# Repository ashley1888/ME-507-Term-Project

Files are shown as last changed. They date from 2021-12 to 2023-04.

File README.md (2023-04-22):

# ME-507-Term-Project
Claw Machine by

Michael Yiu and Ashley Humpal

Fall 2021

The code in this repository aims to control a claw machine and have it go to a destination and pick up objects.

For formal documentation please refer to: https://ashley1888.github.io/ME-507-Term-Project/

This repository contains:

controller_task.cpp

controller_task.h

X_Motor_task.cpp

X_Motor_task.h

Y_Motor_task.cpp

Y_Motor_task.h

Z_Motor_task.cpp

Z_Motor_task.h

Gripper_Motor_task.cpp

Gripper_Motor_task.h

motor_driver.cpp

motor_driver.h

shares.h

main.cpp

Encoder driver files were provided by our professor, Dr. Ridgely and their source code can be found at:
https://github.com/spluttflob/ME507-Support/blob/master/examples/encoder_counter.cpp
https://github.com/spluttflob/ME507-Support/blob/master/examples/encoder_counter.h

Each file contains doxygen style documentation.

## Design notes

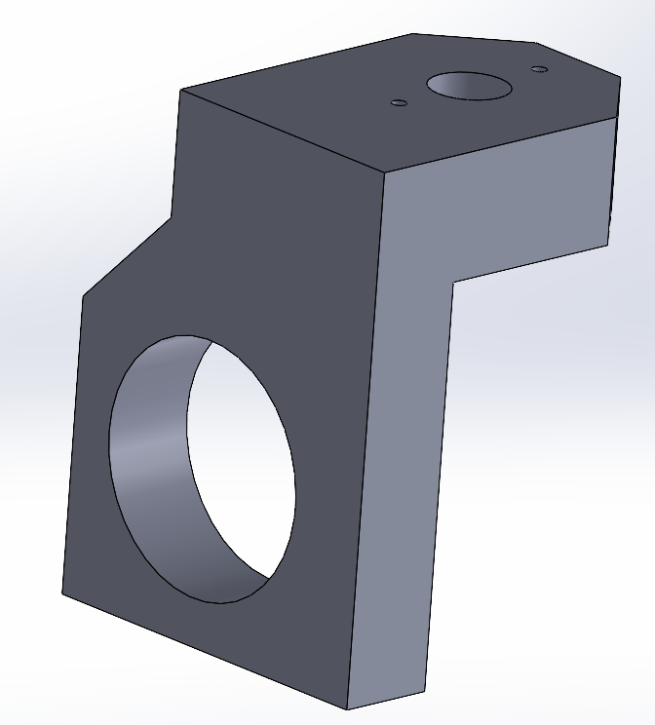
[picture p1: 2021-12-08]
docs/lead_screw_to_gripper.png

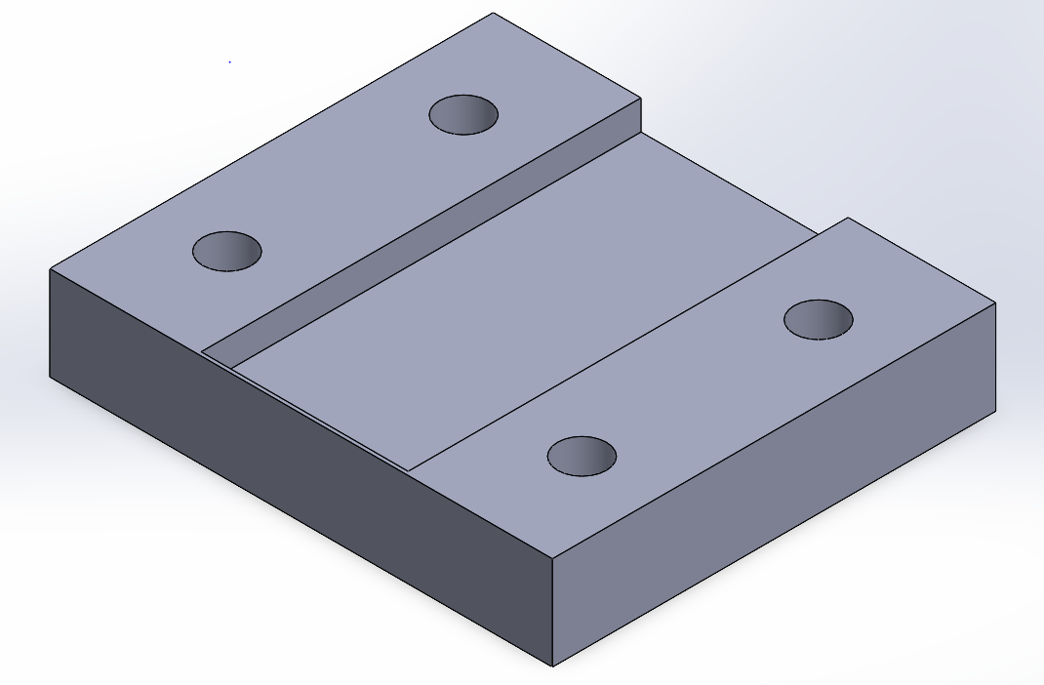
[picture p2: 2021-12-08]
docs/belt_holder.png

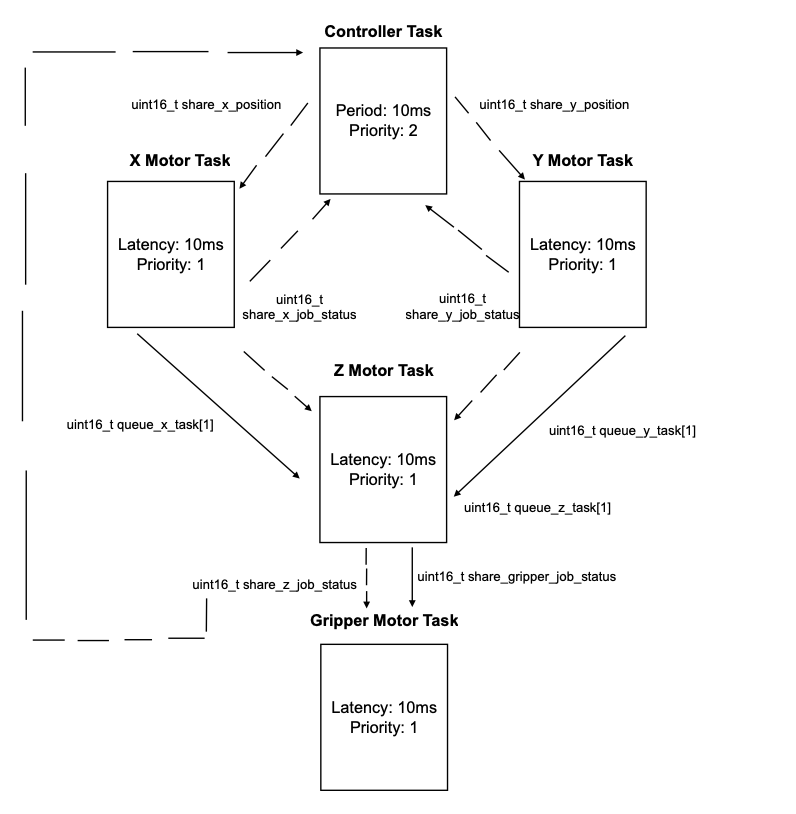
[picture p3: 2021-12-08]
docs/taskdiagram.png

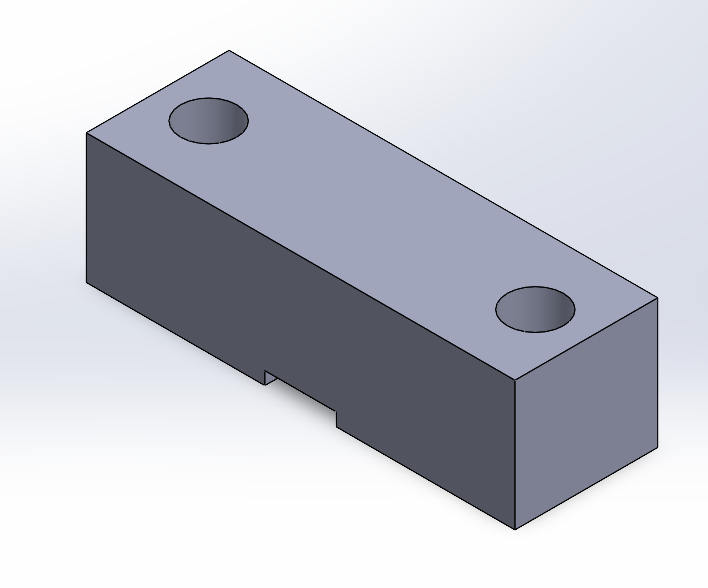
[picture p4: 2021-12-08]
docs/belt_clamp.png

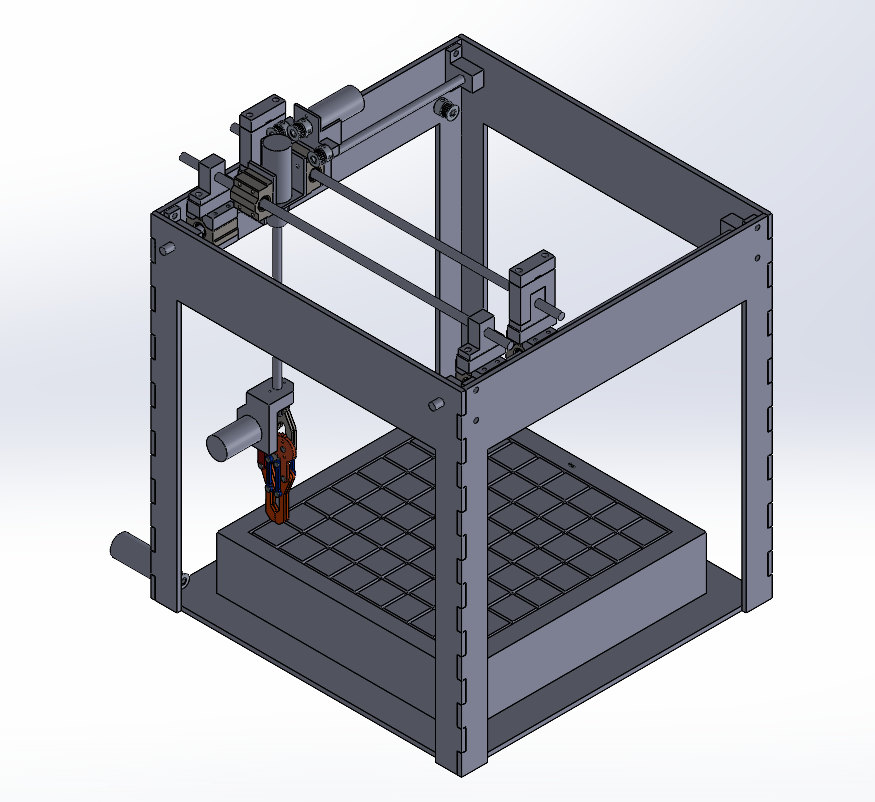
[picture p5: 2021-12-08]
docs/isometric_view.png

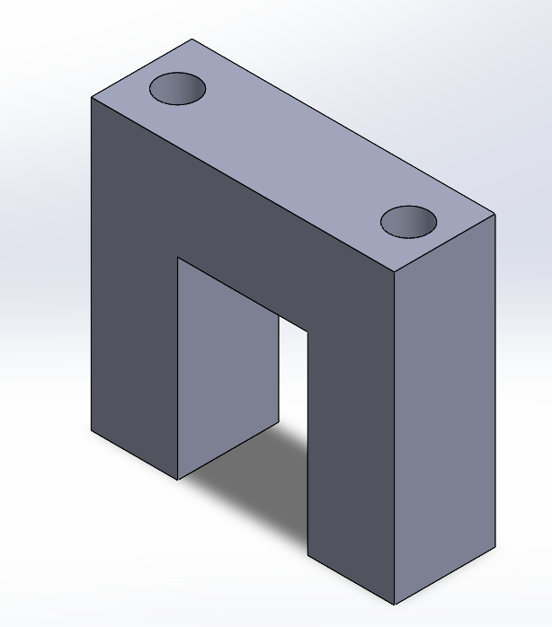
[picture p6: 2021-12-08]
docs/linear_rod_support.png

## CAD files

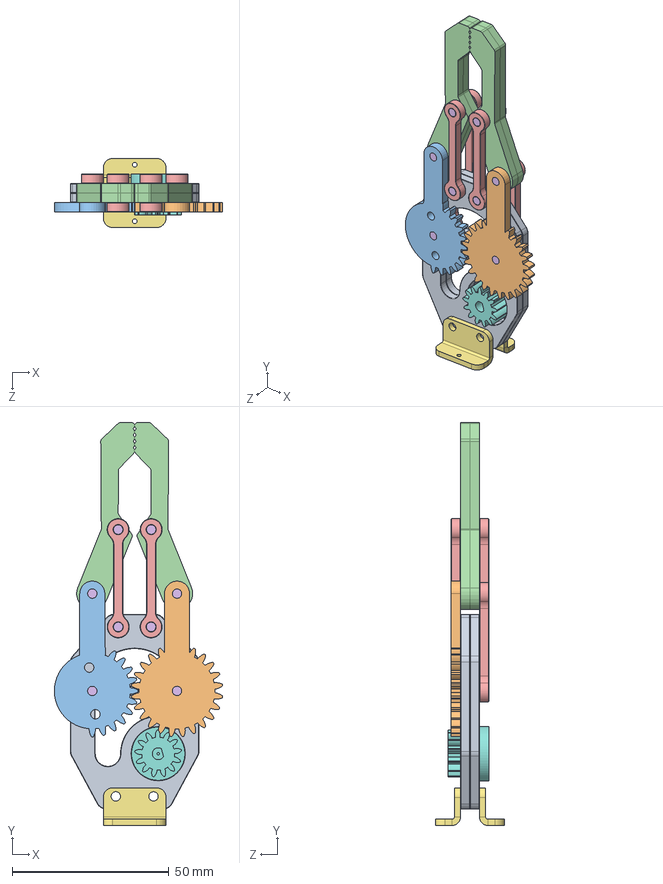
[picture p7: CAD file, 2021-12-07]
CAD/Gripper Assembly.SLDASM
53.6 x 128.4 x 22.0 mm

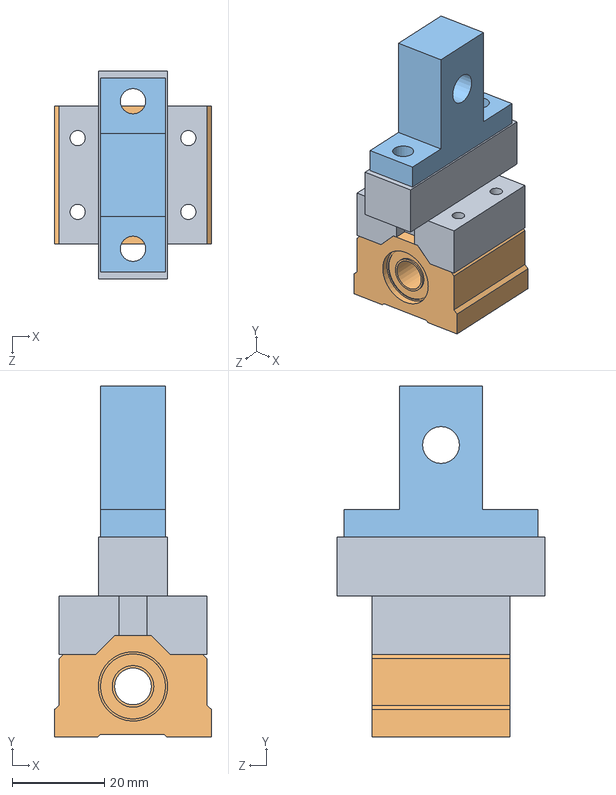
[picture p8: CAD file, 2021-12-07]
CAD/3D Printed Parts/Shaft Bearing.SLDASM
34.1 x 76.1 x 45.0 mm
Shaft Support to Linear Bearing
Linear Ball Bearing
Linear Rod Support

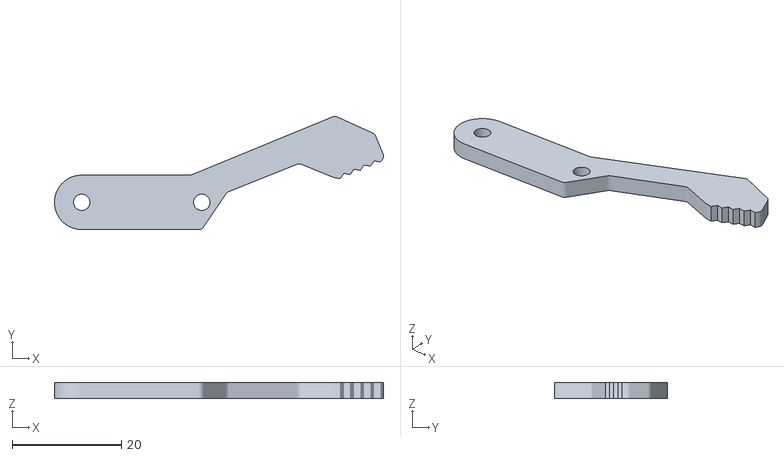
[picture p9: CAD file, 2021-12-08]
CAD/3D Printed Parts/.stl Files/Part1-1 (x4).STL
60.3 x 20.7 x 3.00

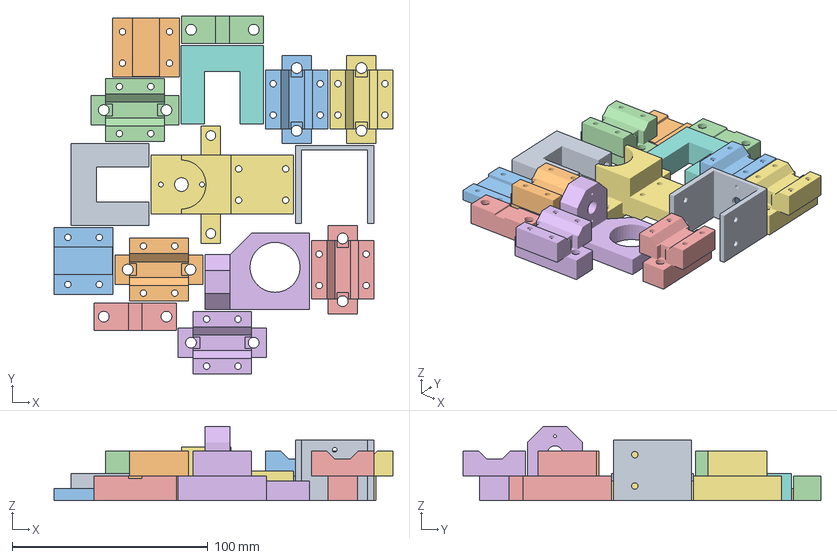
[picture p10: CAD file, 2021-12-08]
CAD/3D Printed Parts/Print Files/Large Pieces.3mf
172.8 x 182.7 x 38.0 mm
Z Motor Support (x1).STL
Shaft Support to Linear Bearing (x6).STL(5)
Shaft Support to Linear Bearing (x6).STL(4)
Shaft Support to Linear Bearing (x6).STL(3)
Shaft Support to Linear Bearing (x6).STL(2)
Shaft Support to Linear Bearing (x6).STL(1)
Shaft Support to Linear Bearing (x6).STL
Linear Rod Support Belt Holder (x2).STL(1)
Linear Rod Support Belt Holder (x2).STL
Belt Holder (x2).STL(1)
Belt Holder (x2).STL
Belt Clamp (x2).STL(1)
Belt Clamp (x2).STL
Lead Screw to Gripper (x1).STL(1)
Motor Support to Linear Bearing (x1).STL

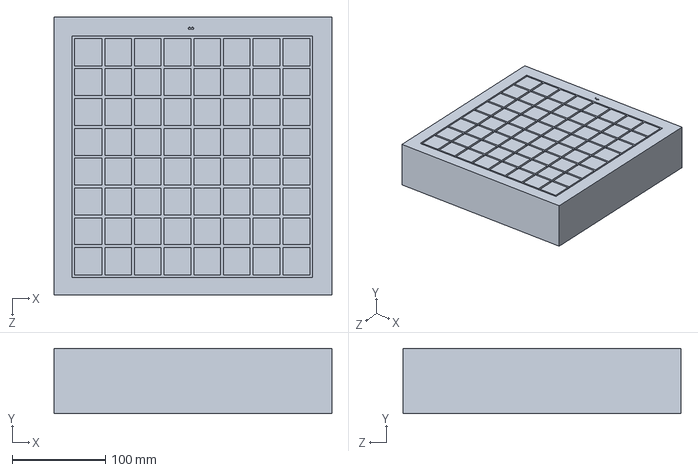
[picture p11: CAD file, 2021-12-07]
CAD/Frame/Chessboard.SLDPRT
298.4 x 69.8 x 298.4 mm

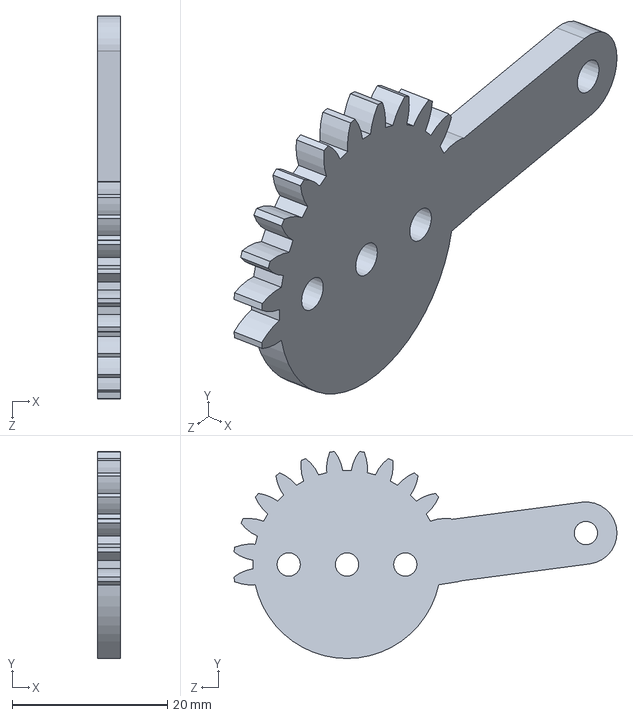
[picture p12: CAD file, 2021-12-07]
CAD/Gripper/part5-5.SLDPRT
3.00 x 26.6 x 49.3 mm

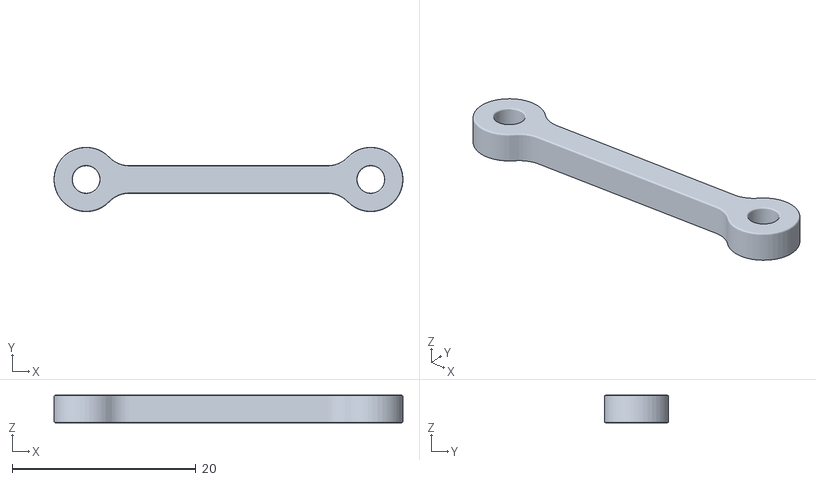
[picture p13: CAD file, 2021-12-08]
CAD/3D Printed Parts/.stl Files/Part2-2 (x6).STL
38.0 x 6.99 x 3.00

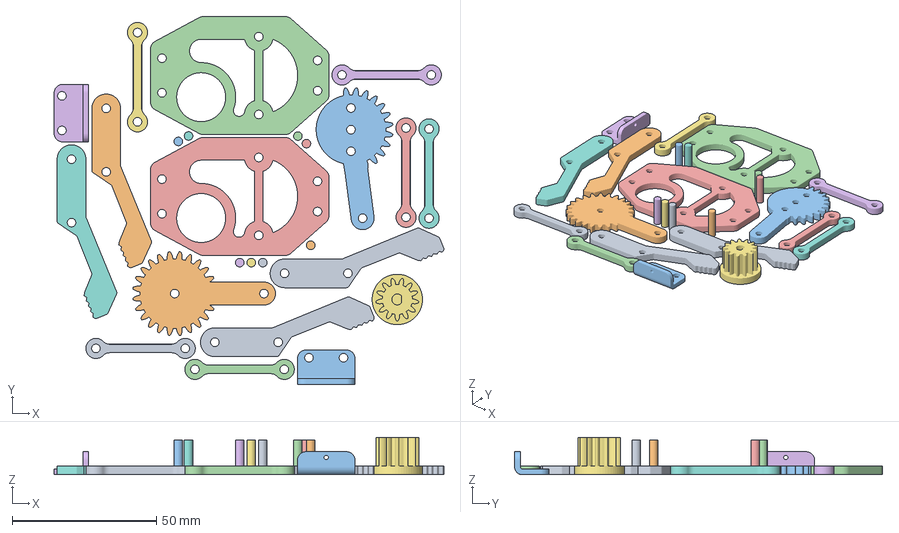
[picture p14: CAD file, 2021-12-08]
CAD/3D Printed Parts/Print Files/Small Pieces.3mf
135.3 x 127.7 x 13.0 mm
Part1-1 (x4).STL
part4-4 (x1).STL
part5-5 (x1).STL
Part2-2 (x6).STL
Part3-3 (x2).STL
Part7-7 (x2).STL
part8-8 (x1).STL
Part1-1 (x4).STL(1)
Part1-1 (x4).STL(2)
Part1-1 (x4).STL(3)
Part7-7 (x2).STL(1)
Part3-3 (x2).STL(1)
Part2-2 (x6).STL(1)
Part2-2 (x6).STL(2)
Part2-2 (x6).STL(3)
Part2-2 (x6).STL(4)
Part2-2 (x6).STL(5)
Part6-6 (x8).STL
Part6-6 (x8).STL(1)
Part6-6 (x8).STL(2)
Part6-6 (x8).STL(3)
Part6-6 (x8).STL(4)
Part6-6 (x8).STL(5)
Part6-6 (x8).STL(6)
Part6-6 (x8).STL(7)

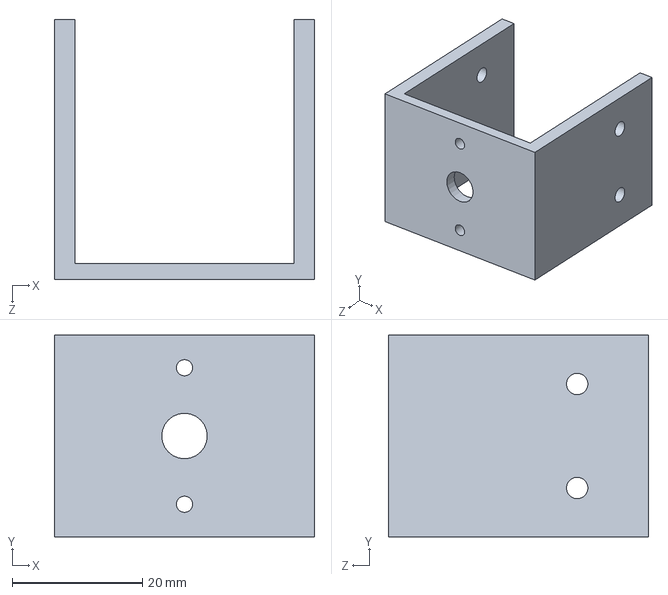
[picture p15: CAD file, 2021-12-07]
CAD/3D Printed Parts/Z Motor Support.SLDPRT
40.0 x 31.0 x 40.0 mm

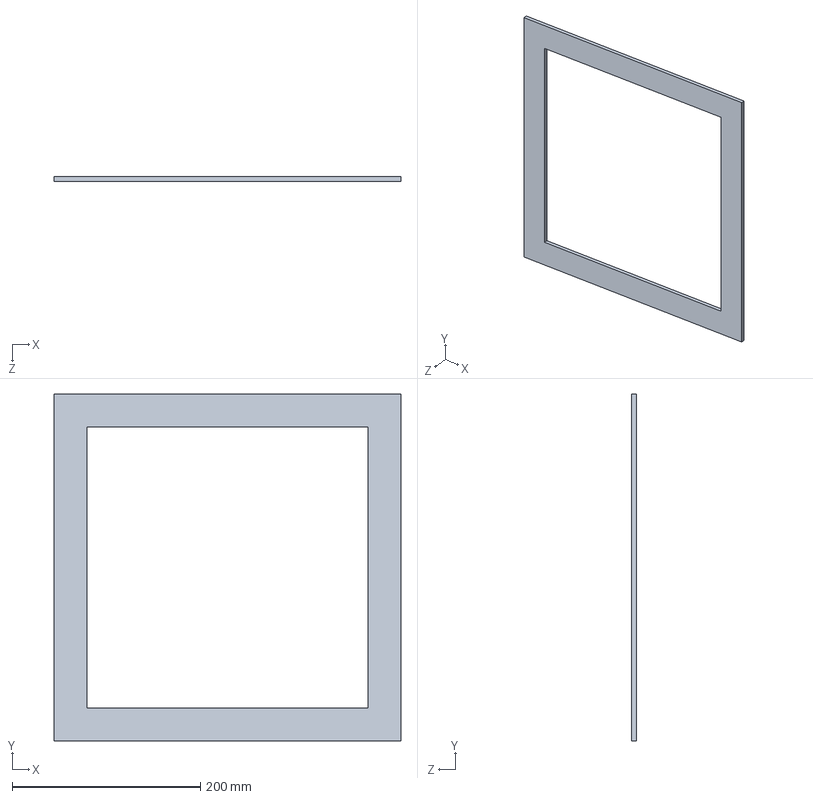
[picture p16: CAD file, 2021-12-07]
CAD/Frame/Mount.SLDPRT
368.3 x 368.3 x 5.33 mm

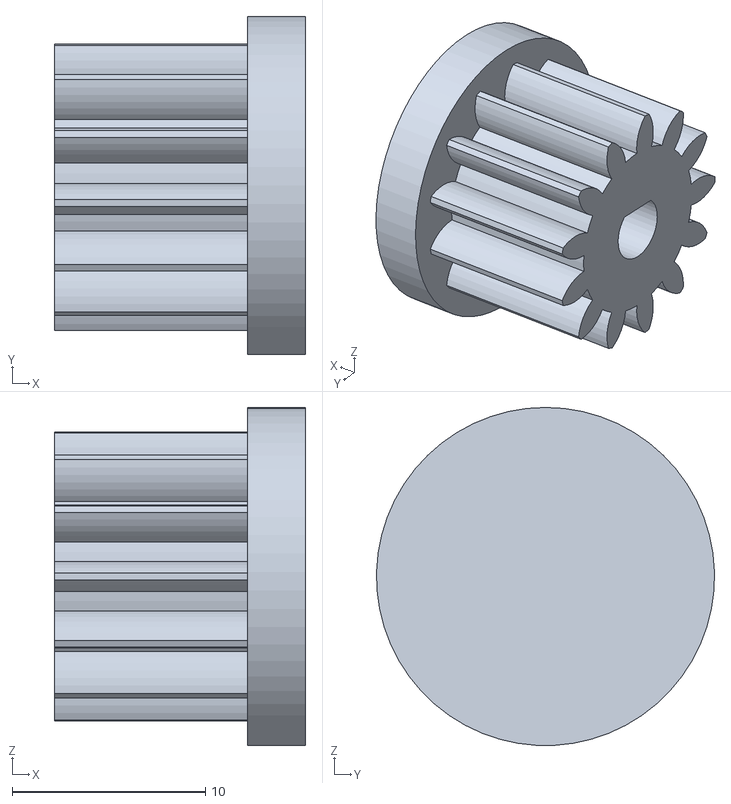
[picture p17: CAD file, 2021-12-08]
CAD/3D Printed Parts/.stl Files/part8-8 (x1).STL
13.0 x 17.5 x 17.5

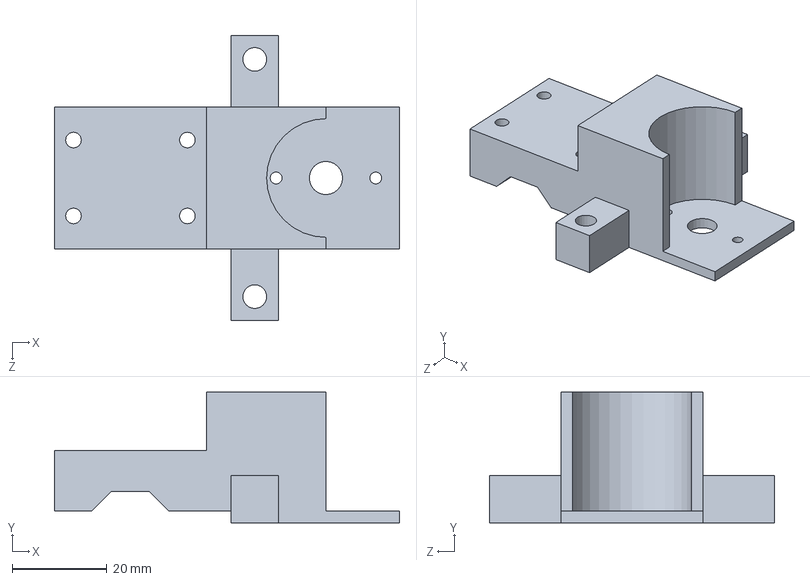
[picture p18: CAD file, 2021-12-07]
CAD/3D Printed Parts/Motor Support to Linear Bearing.SLDPRT
72.7 x 27.5 x 60.0 mm

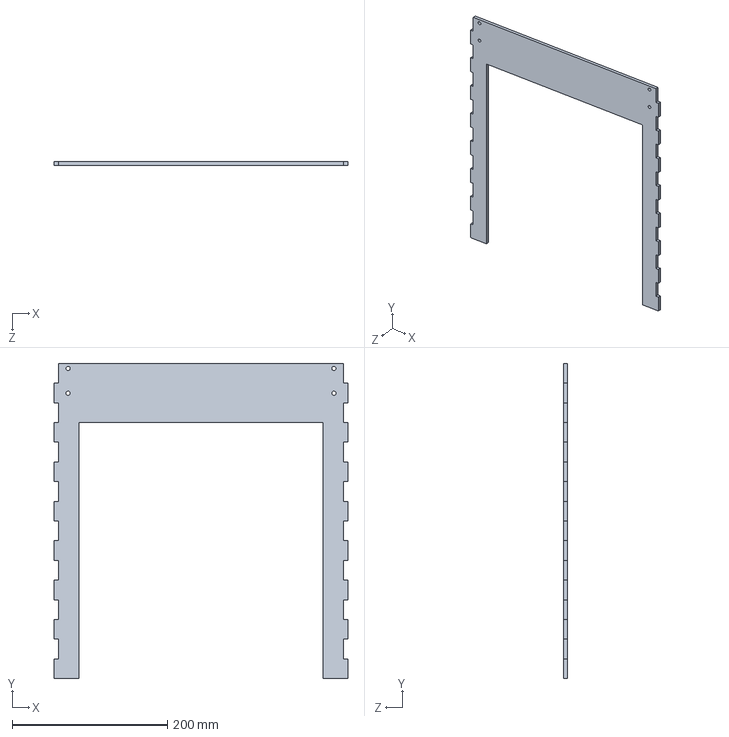
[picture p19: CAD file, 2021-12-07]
CAD/Frame/Long Side.SLDPRT
378.7 x 406.4 x 5.21 mm

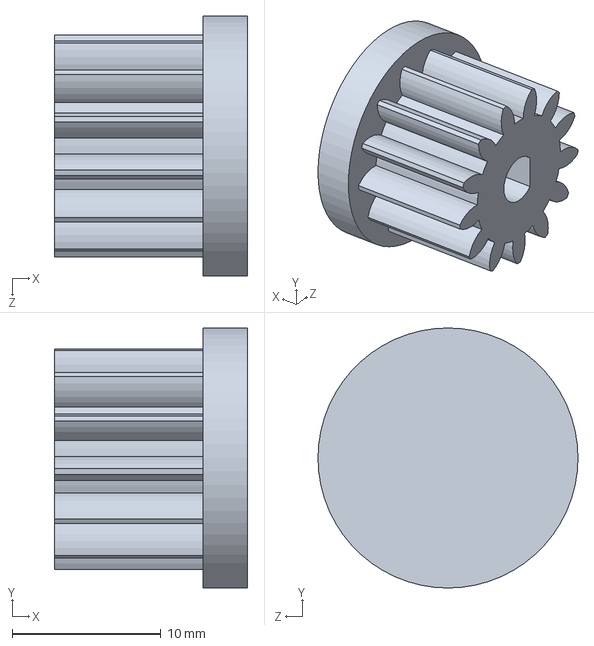
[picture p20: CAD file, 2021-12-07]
CAD/Gripper/part8-8.SLDPRT
13.0 x 17.5 x 17.5 mm

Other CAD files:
CAD/Gripper/Part1-1.SLDPRT
CAD/3D Printed Parts/.stl Files/part5-5 (x1).STL
CAD/3D Printed Parts/Belt Clamp.SLDPRT
CAD/3D Printed Parts/.stl Files/Belt Clamp (x2).STL
CAD/3D Printed Parts/.stl Files/Belt Holder (x2).STL
CAD/3D Printed Parts/.stl Files/Lead Screw to Gripper (x1).STL
CAD/3D Printed Parts/.stl Files/Linear Rod Support Belt Holder (x2).STL
CAD/3D Printed Parts/.stl Files/Motor Support to Linear Bearing (x1).STL
CAD/3D Printed Parts/.stl Files/Part3-3 (x2).STL
CAD/3D Printed Parts/.stl Files/Part6-6 (x8).STL
CAD/3D Printed Parts/.stl Files/Part7-7 (x2).STL
CAD/3D Printed Parts/.stl Files/Shaft Support to Linear Bearing (x6).STL
CAD/3D Printed Parts/.stl Files/Z Motor Support (x1).STL
CAD/3D Printed Parts/.stl Files/part4-4 (x1).STL
CAD/3D Printed Parts/Belt Holder.SLDPRT
CAD/3D Printed Parts/Lead Screw to Gripper.SLDPRT
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

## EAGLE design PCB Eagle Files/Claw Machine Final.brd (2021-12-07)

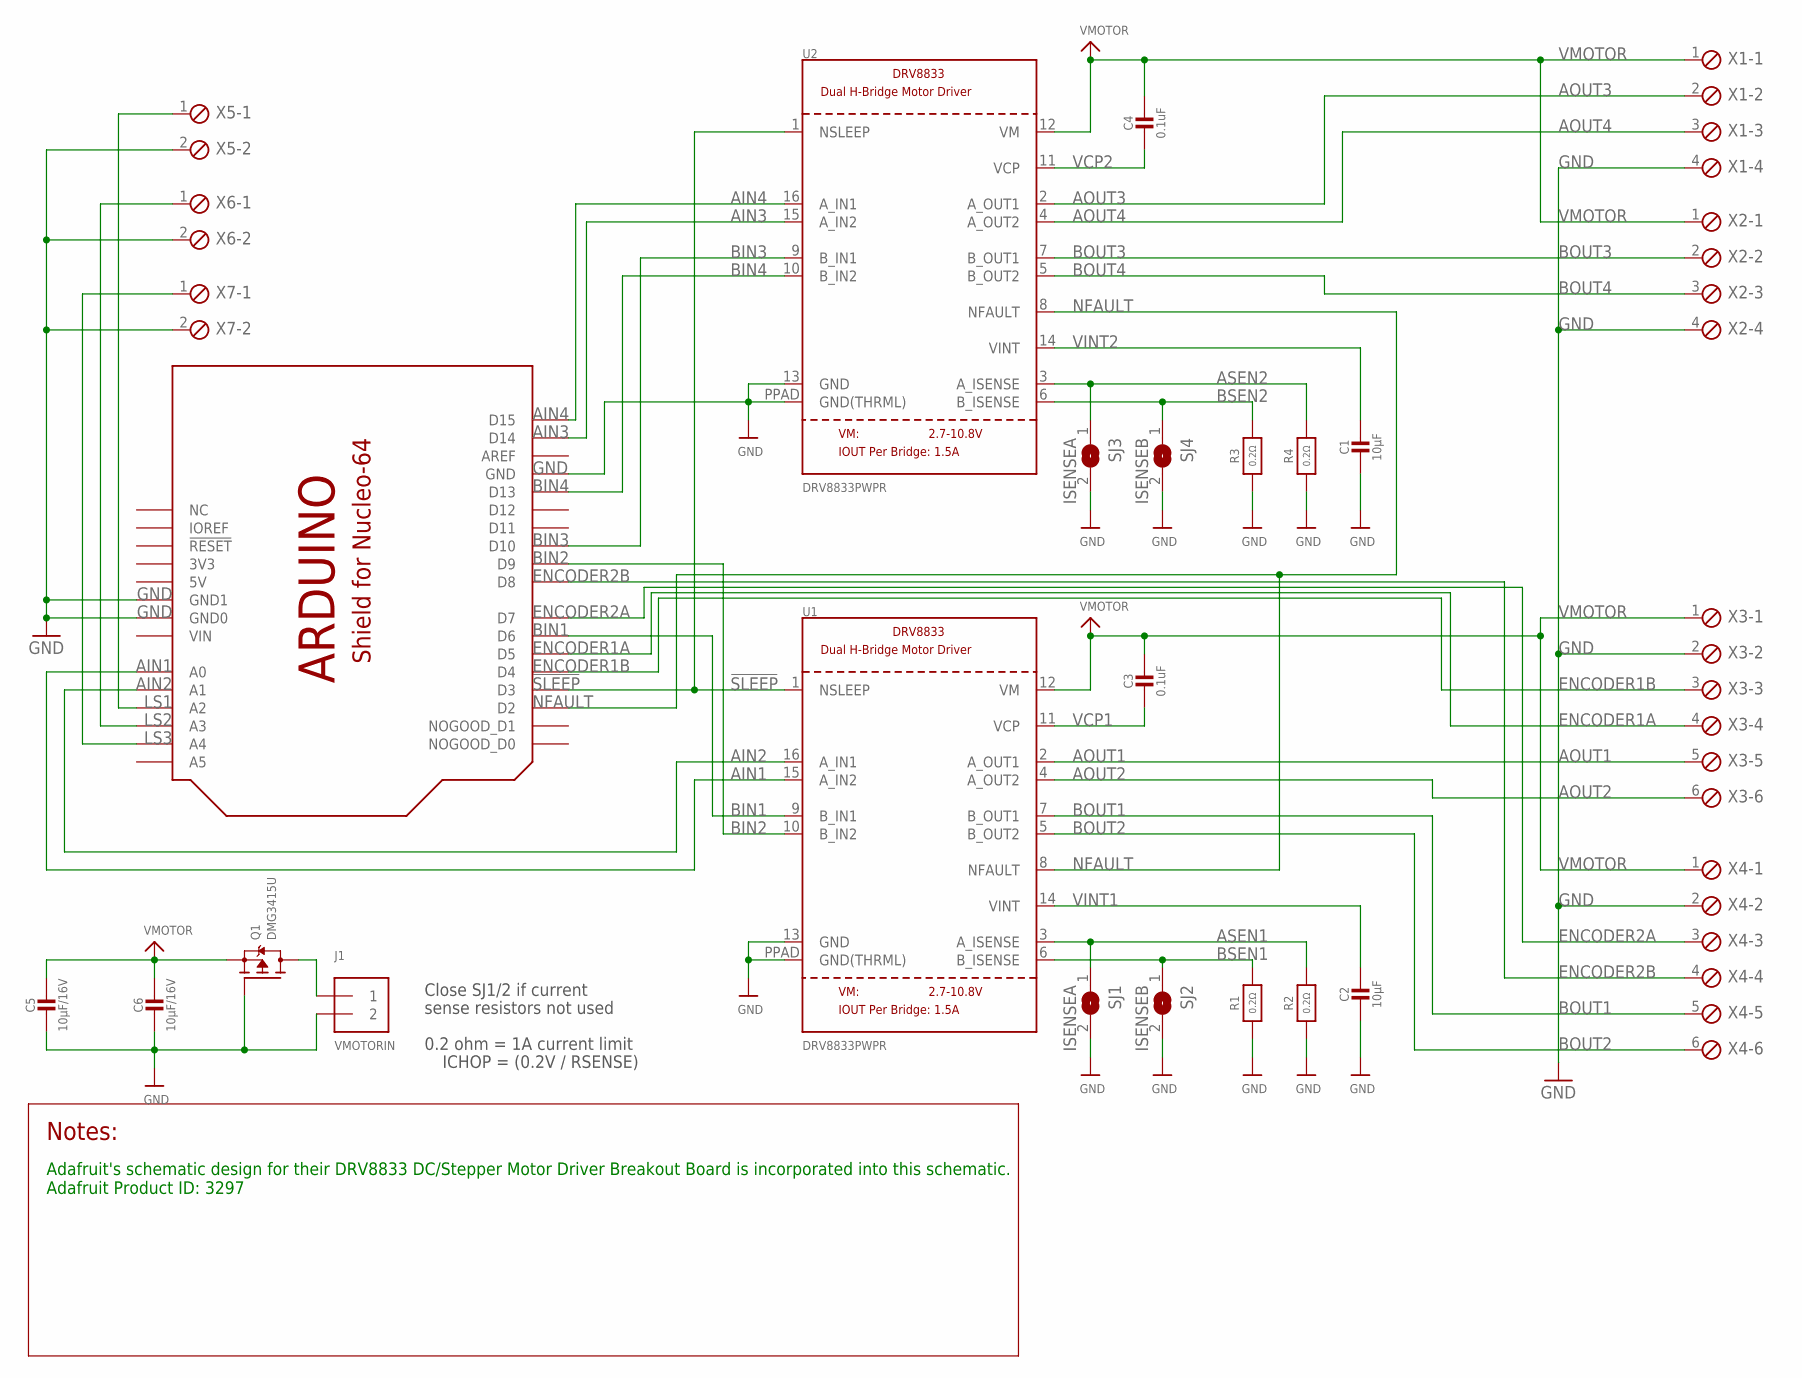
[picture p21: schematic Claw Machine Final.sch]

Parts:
C1, C2: 10µF; 0805-NO
C3, C4: 0.1uF; 0805-NO
C5, C6: 10µF/16V; 0805-NO
J1: VMOTORIN; TERMBLOCK_1X2-3.5MM
Q1: DMG3415U; SOT23-WIDE
R1, R2, R3, R4: 0.2Ω; _1206
SJ1, SJ3: ISENSEA; SOLDERJUMPER_ARROW_NOPASTE
SJ2, SJ4: ISENSEB; SOLDERJUMPER_ARROW_NOPASTE
U1, U2: DRV8833PWPR; HTSSOP16
U$1: SHIELD_FOR_NUCLE0_64_STANDARD; SHIELD_FOR_NUCLEO_64_STD
X1, X2: SCREWTERM_4P_254; 4POL254
X3, X4: SCREWTERM_6P_254; 6POL254
X5, X6, X7: SCREWTERM_2P_254; 2POL254

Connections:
3V3: U$1.3V (3V3)
5V: U$1.5V
!SLEEP: U1.1 (NSLEEP), U2.1 (NSLEEP), U$1.D3
AIN1: U1.15 (A_IN2), U$1.A0
AIN2: U1.16 (A_IN1), U$1.A1
AIN3: U2.15 (A_IN2), U$1.D14
AIN4: U2.16 (A_IN1), U$1.D15
AOUT1: U1.2 (A_OUT1), X3.5
AOUT2: U1.4 (A_OUT2), X3.6
AOUT3: U2.2 (A_OUT1), X1.2
AOUT4: U2.4 (A_OUT2), X1.3
ASEN1: R2.2, SJ1.1, U1.3 (A_ISENSE)
ASEN2: R4.2, SJ3.1, U2.3 (A_ISENSE)
BIN1: U1.9 (B_IN1), U$1.D6
BIN2: U1.10 (B_IN2), U$1.D9
BIN3: U2.9 (B_IN1), U$1.D10
BIN4: U2.10 (B_IN2), U$1.D13
BOUT1: U1.7 (B_OUT1), X4.5
BOUT2: U1.5 (B_OUT2), X4.6
BOUT3: U2.7 (B_OUT1), X2.2
BOUT4: U2.5 (B_OUT2), X2.3
BSEN1: R1.2, SJ2.1, U1.6 (B_ISENSE)
BSEN2: R3.2, SJ4.1, U2.6 (B_ISENSE)
ENCODER1A: U$1.D5, X3.4
ENCODER1B: U$1.D4, X3.3
ENCODER2A: U$1.D7, X4.3
ENCODER2B: U$1.D8, X4.4
GND: C1.2, C2.2, C5.2, C6.2, J1.2, Q1.1 (G), R1.1, R2.1, R3.1, R4.1, SJ1.2, SJ2.2, SJ3.2, SJ4.2, U1.13 (GND), U1.PPAD (GND(THRML)), U2.13 (GND), U2.PPAD (GND(THRML)), U$1.GND, U$1.GND1 (GND0), U$1.GND2 (GND1), X1.4, X2.4, X3.2, X4.2, X5.2, X6.2, X7.2
LS1: U$1.A2, X5.1
LS2: U$1.A3, X6.1
LS3: U$1.A4, X7.1
NFAULT: U1.8 (NFAULT), U2.8 (NFAULT), U$1.D2
PWRIN: J1.1, Q1.3 (D)
VCP1: C3.2, U1.11 (VCP)
VCP2: C4.2, U2.11 (VCP)
VIN: U$1.VIN
VINT1: C2.1, U1.14 (VINT)
VINT2: C1.1, U2.14 (VINT)
VMOTOR: C3.1, C4.1, C5.1, C6.1, Q1.2 (S), U1.12 (VM), U2.12 (VM), X1.1, X2.1, X3.1, X4.1

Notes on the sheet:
Close SJ1/2 if current
sense resistors not used
0.2 ohm = 1A current limit
ICHOP = (0.2V / RSENSE)
Adafruit's schematic design for their DRV8833 DC/Stepper Motor Driver Breakout Board is incorporated into this schematic. Adafruit Product ID: 3297

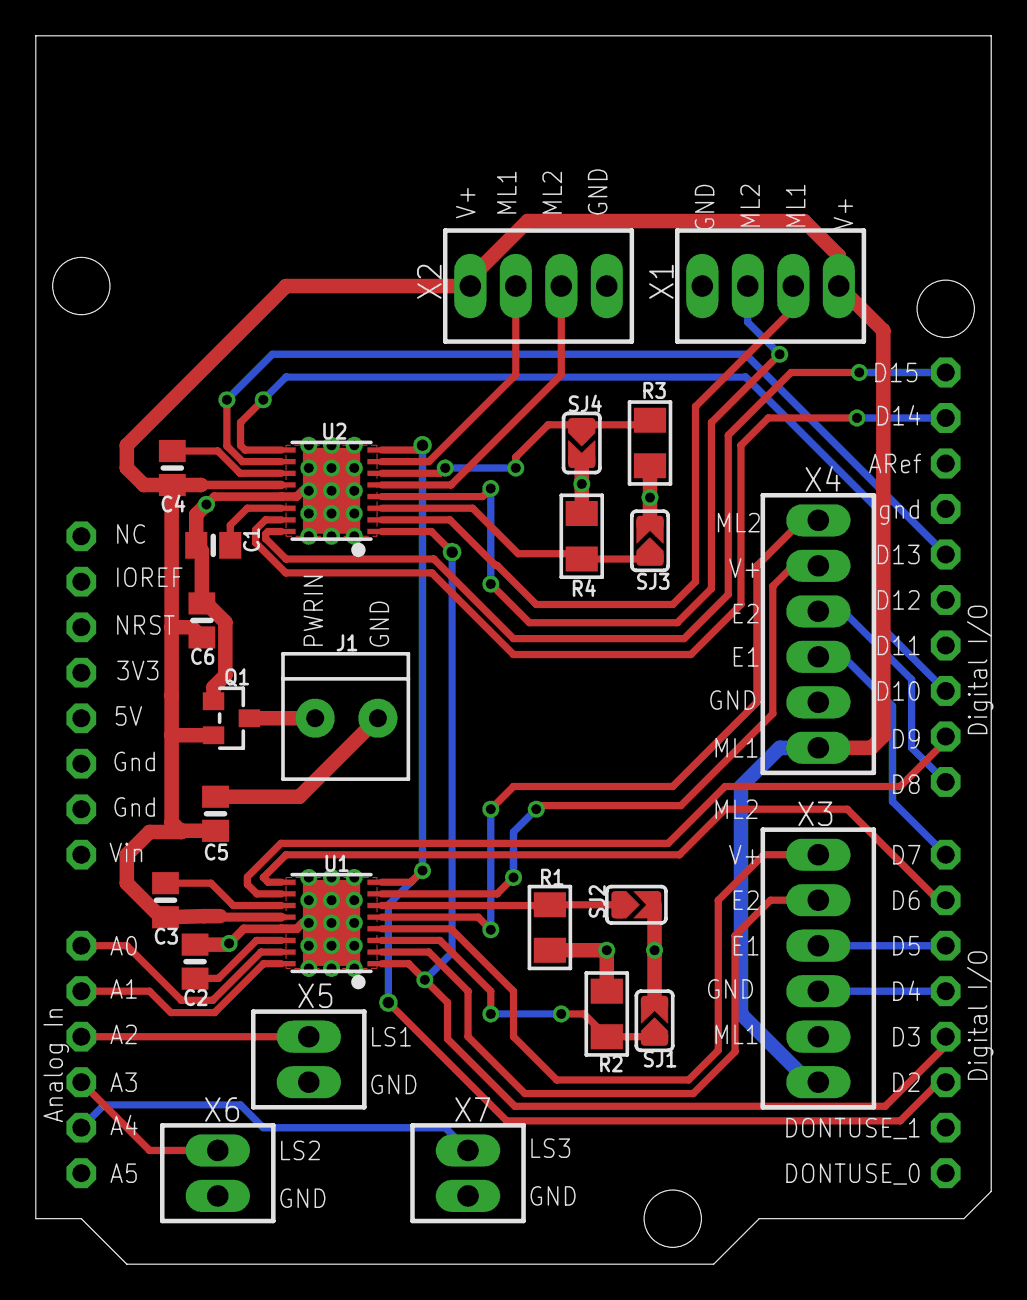
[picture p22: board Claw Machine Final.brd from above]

Board: 2 copper layers, 53.3 x 68.6 mm, 26 parts (0 on the bottom side), 36 nets.

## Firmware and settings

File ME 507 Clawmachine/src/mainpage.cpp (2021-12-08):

/** @file mainpage.cpp
 *    
 *  @mainpage
 * 
 *  @section page_intro Introduction
 * 
 *  @image html isometric_view.png "Claw Machine Isometric View" width=75%
 * 
 *  This website contains all relevant software information concerning our ME 507 Term project the Claw Machine.
 *  At a high level what occurs in our project is that the controller task reads the user’s input position and sends that location to the x and y-motor tasks.
 *  After reading the position, the two x and y-motors actuate and continue to rotate until the encoder indicates that they have reached the correct position, 
 *  to a certain allowable tolerance. Once the correct x and y-positions have been reached, the z-motor activates for a predetermined length of time, descending the gripper. 
 *  When the end effector reaches its destination, the gripper-motor actuates for a different predetermined length of time to close and grasps the object.
 * 
 *  The encoder driver files were supplied by our professor, Dr. Ridgely and their source code can be found at: 
 *  @c https://github.com/spluttflob/ME507-Support/blob/master/examples/encoder_counter.cpp
 *  @c https://github.com/spluttflob/ME507-Support/blob/master/examples/encoder_counter.h
 * 
 *  @author Ashley Humpal and Michael Yiu
 *  @date 2021-01-Dec
 * 
 *  @page page_diagram Task Diagram
 *  @section sec_diagram Task Diagram
 *  Below is an image of the task diagram used for this project
 *  @image html taskdiagram.png "Figure 1: Claw Machine Task Diagram" width=75%
 * 
 *  @page page_control Controller Task
 *  @section sec_control Controller Task
 *    This task is the controller task of the claw machine. 
 *    It has the user enter a value between 1 and 64, where
 *    each value represents a position on an 8x8 chessboard.
 *    Once a value has been entered, the controller task sends
 *    the responding x and y-values to the x and y-motors. The
 *    purpose of the value is so that the motor encoders know
 *    when they have reached their destination.
 *    It's source code can be found at: 
 * 
 *    @c https://github.com/ashley1888/ME-507-Term-Project/blob/main/ME%20507%20Clawmachine/src/controller_task.cpp
 * 
 *  @page page_motor Motor Tasks
 *  @section sec_x X-Motor Task
 *    This task for the user to give it a reference x-position value,
 *    which is obtained from the controller task. Once a value has
 *    been obtained, the motor powers on and only turns off once the
 *    encoder is within 50 ticks of the destination.
 *    It's source code can be found at: 
 * 
 *    @c https://github.com/ashley1888/ME-507-Term-Project/blob/main/ME%20507%20Clawmachine/src/X_Motor_Task.cpp
 *  @section sec_y Y-Motor Task
 *    This task waits for the user to give it a refernce y-position value,
 *    which is obtained from the controller task. Once a value has
 *    been obtained, the motor powers on and only turns off once the
 *    encoder is within 50 ticks of the destination.
 *    It's source code can be found at: 
 * 
 *    @c https://github.com/ashley1888/ME-507-Term-Project/blob/main/ME%20507%20Clawmachine/src/Y_Motor_Task.cpp
 *  @section sec_z Z-Motor Task
 *    This task only runs once the x and y-tasks have indicated that
 *    they have been completed. The z-motors will turn off once the
 *    specific length of time has elapsed.
 *    It's source code can be found at: 
 * 
 *    @c https://github.com/ashley1888/ME-507-Term-Project/blob/main/ME%20507%20Clawmachine/src/Z_Motor_Task.cpp
 *  @section sec_gripper Gripper-Motor Task
 *    This task only runs once the z-tasks has indicated that
 *    it has completed. The gripper-motors will turn on for a
 *    specified length of time to grasp an object, then wait a
 *    different specified length of time before releasing it.
 *    It's source code can be found at: 
 * 
 *    @c https://github.com/ashley1888/ME-507-Term-Project/blob/main/ME%20507%20Clawmachine/src/Gripper_Motor_Task.cpp
 *  @page page_3D 3D Printed Parts
 *  @section sec_3D 3D Printed Parts
 *    Seven 3D printed parts were originally designed and created for this project.
 *    An image of each of them can be seen below.
 *    @image html belt_clamp.png "Part 1: X-axis Belt Clamp" width=75%
 *    @image html linear_rod_support.png "Part 2: Linear Rod Support Belt Holder" width=75%
 *    @image html shaft_support_to_linear_bearing.png "Part 3: Shaft Support to Linear Bearing" width=75%
 *    @image html belt_holder.png "Part 4: Y-axis Belt Clamp" width=75%
 *    @image html x_motor_support.png "Part 5: X-motor Support" width=75%
 *    @image html z_motor_support.png "Part 6: Z-motor Support" width=75%
 *    @image html lead_screw_to_gripper.png "Part 7: Gripper-motor and Gripper Support" width=75%
 * 
 *    The gripper used for this project was not originally created, it was found 
 *    off GrabCAD, and open-source CAD library. Below is an image of the gripper.
 *    @image html gripper.png "Gripper Model" width=75%
 * 
 *    This particular gripper was designed by Avinash Bhashkar, and its source can be found at:
 *    @c https://grabcad.com/library/robotic-gripper-and-end-effector-1
 */

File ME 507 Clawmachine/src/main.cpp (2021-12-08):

/** @file main.cpp
 *    This file contains the controller and motor tasks needed to operate the claw machine. 
 *    The motor tasks are for the X axis, Y axis, Z axis, and for the gripper. 
 *    The controller tasks reads the user input and sends it to the motor tasks.
 *
 *  @author Ashley Humpal and Michael Yiu
 *  @date 2021-01-Dec

 */
#include <Arduino.h>
#include <PrintStream.h>

#if (defined STM32L4xx || defined STM32F4xx)
#include <STM32FreeRTOS.h>
#endif

#include "shares.h"

#include "controller_task.h"
#include "X_Motor_Task.h"
#include "Y_Motor_Task.h"
#include "Z_Motor_Task.h"
#include "Gripper_Motor_Task.h"

// Shared variables and queues initialized 
Queue<uint16_t> queue_x_task(1, "X_Status");
Queue<uint16_t> queue_y_task(1, "Y_Status");
Queue<uint16_t> queue_z_task(1, "Z_Status");

Share<uint16_t> share_x_position;
Share<uint16_t> share_y_position;
Share<uint16_t> share_x_job_status;
Share<uint16_t> share_y_job_status;
Share<uint16_t> share_z_job_status;
Share<uint16_t> share_gripper_job_status;
 
/** @brief   Arduino setup function which runs once at program startup.
 *  @details This function sets up a serial port for communication and creates the
 *           tasks which will be run.
 */
void setup()
{
  Serial.begin(115200);
  delay(1500);

  xTaskCreate(task_controller,    // Task function
              "Control",          // Name in diagnostic printouts
              1000,               // Stack size in bytes
              NULL,               // Parameters for task function
              2,                  // Task priority
              NULL);              // Handle to task struct
  xTaskCreate(task_x_motor,       // Task function
              "X_Motor",          // Name in diagnostic printouts
              1000,               // Stack size in bytes
              NULL,               // Parameters for task function
              1,                  // Task priority
              NULL);              // Handle to task struct
  xTaskCreate(task_y_motor,       // Task function
              "Y_Motor",          // Name in diagnostic printouts
              1000,               // Stack size in bytes
              NULL,               // Parameters for task function
              1,                  // Task priority
              NULL);              // Handle to task struct
  xTaskCreate(task_z_motor,       // Task function
              "Z_Motor",          // Name in diagnostic printouts
              1000,               // Stack size in bytes
              NULL,               // Parameters for task function
              1,                  // Task priority
              NULL);              // Handle to task struct
  xTaskCreate(task_gripper_motor, // Task function
              "Gripper_Motor",    // Name in diagnostic printouts
              1000,               // Stack size in bytes
              NULL,               // Parameters for task function
              1,                  // Task priority
              NULL);              // Handle to task struct

  // STM32duino requires that the FreeRTOS scheduler be manually started
  vTaskStartScheduler();
}
void loop()
{
}

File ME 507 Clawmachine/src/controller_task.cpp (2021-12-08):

/** @file controller_task.cpp
 *    This file is the controller task of the claw machine. 
 *    It has the user enter a value between 1 and 64, where
 *    each value represents a position on an 8x8 chessboard.
 *    Once a value has been entered, the controller task sends
 *    the responding x and y-values to the x and y-motors. The
 *    purpose of the value is so that the motor encoders know
 *    when they have reached their destination.
 * 
 *  @author Ashley Humpal and Michael Yiu 
 *  @date   2021-Dec-06 
 */

#include <Arduino.h> 
#include <PrintStream.h>
#include <STM32FreeRTOS.h>
#include "controller_task.h"
#include "shares.h"

/** @brief   Task which reads the user's input sends the appropriate
 *           values through shared variables.
 *  @details Assigns an x and y-position to every square of an 8x8
 *           chessboard and sends the appropriate value depending
 *           on the user's input. When the other tasks are running,
 *           this task will wait until they send back a "done" 
 *           indicator, forcing the user to wait until then.
 *  @param   p_params A pointer, which is ignored, to no parameters
 */
void task_controller(void *p_params)
{
    uint16_t x_task_done = 1;  // Variable representing status of the completion of the X_Motor_Task
    uint16_t y_task_done = 1;  // Variable representing status of the completion of the Y_Motor_Task
    uint16_t z_task_done = 1;  // Variable representing status of the completion of the Z_Motor_Task
    uint16_t gripper_task_done = 1; // Variable representing status of the completion of the Gripper_Motor_Task
    uint16_t task_done = 1; // Variable representing status of the completion of all motor tasks
    uint8_t one_pos = (pow(2, 16) - 1) / 8; // Variable representing the rotation value needed to move one square on the chess board
    for (;;)
    {
        if (x_task_done && y_task_done && z_task_done && gripper_task_done) // Checks if all motor tasks are completed 
        {
            if Serial.available() > 0) // Checks whether user has input anything to the serial monitor 
            {
                uint16_t numberval = Serial.parseInt(); // Reads user input integer values
                uint16_t list = +numberval; //Puts the read numbers together in case there's more than one
                delay(5000); //Waits a little to let user finish entering numbers

                // Beginning of if else conditionals to set shared position variables based on what the user input

                    if (list == 1) // If user entered 1
                    {
                        share_x_position.put(one_pos); // Set the shared user x position as the following
                        share_y_position.put(one_pos); // Set the shared user y position as the following
                    }
                    else if (list == 2)
                    {
                        share_x_position.put(one_pos * 2);
                        share_y_position.put(one_pos);
                    }
                    else if (list == 3)
                    {
                        share_x_position.put(one_pos * 3);
                        share_y_position.put(one_pos);
                    }
                    else if (list == 4)
                    {
                        share_x_position.put(one_pos * 4);
                        share_y_position.put(one_pos);
                    }
                    else if (list == 5)
                    {
                        share_x_position.put(one_pos * 5);
                        share_y_position.put(one_pos);
                    }
                    else if (list == 6)
                    {
                        share_x_position.put(one_pos * 6);
                        share_y_position.put(one_pos);
                    }
                    else if (list == 7)
                    {
                        share_x_position.put(one_pos * 7);
                        share_y_position.put(one_pos);
                    }
                    else if (list == 8)
                    {
                        share_x_position.put(one_pos * 8);
                        share_y_position.put(one_pos);
                    }
                
                    // row 2
                    else if (list == 9)
                    {
                        share_x_position.put(one_pos);
                        share_y_position.put(one_pos * 2);
                    }
                    else if (list == 10)
                    {
                        share_x_position.put(one_pos * 2);
                        share_y_position.put(one_pos * 2);
                    }
                    else if (list == 11)
                    {
                        share_x_position.put(one_pos * 3);
                        share_y_position.put(one_pos * 2);
                    }
                    else if (list == 12)
                    {
                        share_x_position.put(one_pos * 4);
                        share_y_position.put(one_pos * 2);
                    }
                    else if (list == 13)
                    {
                        share_x_position.put(one_pos * 5);
                        share_y_position.put(one_pos * 2);
                    }
                    else if (list == 14)
                    {
                        share_x_position.put(one_pos * 6);
                        share_y_position.put(one_pos * 2);
                    }
                    else if (list == 15)
                    {
                        share_x_position.put(one_pos * 7);
                        share_y_position.put(one_pos * 2);
                    }
                    else if (list == 16)
                    {
                        share_x_position.put(one_pos * 8);
                        share_y_position.put(one_pos * 2);
                    }
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

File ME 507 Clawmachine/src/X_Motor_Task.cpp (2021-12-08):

/** @file X_Motor_Task.cpp
 *    This file contains the implementation of the x-motor task.
 *    It waits for the user to give it a refernce position value,
 *    which is obtained from the controller task. Once a value has
 *    been obtained, the motor powers on and only turns off once the
 *    encoder is within 50 ticks of the destination.
 *
 *  @author Michael Yiu and Ashley Humpal
 *  @date   2021-Dec-01
 */
#include <Arduino.h>
#include <PrintStream.h>
#include <STM32FreeRTOS.h>

#include "shares.h"
#include "motor_driver.h"
#include "encoder_counter.h"
#include "X_Motor_Task.h"

/** @brief   X-motor task
 *  @details Turns on the x-motor once a value has been given to it
 *           from the controller task. It turns off once the encoder
 *           is withing 50 ticks of the supplied reference position.
 *  @param   p_params A pointer, which is ignored, to no parameters
 */
void task_x_motor(void *p_params)
{
  // Serial << "Initializing X motor and encoder...";
  MotorDriver X_motor(PA0, PA1, PB3, PA10); // Creating x-motor object
  STM32Encoder X_encoder(TIM3, PB4, PB5); // Creating encoder object for x-motor
  // Serial << "done." << endl;

  X_motor.enable(); // Turn on motor

  uint16_t user_x = 0; // Local variable created to hold share value

  for (;;)
  {
    share_x_position.get(user_x); // If available get an x-value from the controller task

    if(user_x) // Initially zero so that if the controller has not yet supplied a value, the if statement will not evaluate
    {
      //  Serial << "My X position is: " << X_encoder.getCount() << endl; // Print encoder position
       X_motor.setduty(-100); // Set duty 

      if (abs(X_encoder.getCount() - user_x) <= 50) // If close enough to desired position, turn off motor and indicate that task is complete
      {
        X_motor.setduty(0); // set duty to 0 
        share_x_position.put(0); // put 0 into shared variable
        share_x_job_status.put(1); // put 1 into shared job status variable to indicate task done
        queue_x_task.put(1); // put 1 into queue
      }
    }
  }
}

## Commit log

2021-11-23 Creating initial motor and encoder drivers
2021-11-23 Ridgley's Encoder Drivers added
2021-11-23 Encoder Task created
2021-11-24 modifying motor1 task so it checks shared values
2021-11-28 Trying to fix shares
    [controller_task.cpp, main.cpp]
2021-11-28 added shares job status and stopping motor when back at origin
2021-11-28 didnt get a chance to review code, worked on the report and prepped some files for 3D printing
2021-11-28 Fixed shares lib deps issue
    [controller_task.cpp, main.cpp]
2021-11-29 creating task error fixed and new function error found
    [main.cpp]
2021-11-30 Moved files to new folder, and changed encoder code to work for PA0 and PA1
2021-11-30 motor 1 task
2021-12-01 x&y motor tasks complete
2021-12-01 testing two motors
2021-12-01 cleaned up motor tasks
2021-12-01 adding shares to motor driver
2021-12-01 formating, added shares and added tasks: Z motor and Gripper motor
2021-12-01 Z motor task
2021-12-01 changed to correct pins (top right)
    [Z_Motor_Task.cpp]
2021-12-01 was missing a comma
    [main.cpp]
2021-12-01 commented code out to test (shares.put() or .get() is not working as expected)
    [X_Motor_Task.cpp, Y_Motor_Task.cpp, controller_task.cpp]
2021-12-02 all 4 motor tasks created
2021-12-02 faulted func added to motor driver
2021-12-02 nfault pin
2021-12-02 motor inertia
2021-12-02 x motor task complete with shares
2021-12-02 x&y motors integrated w shares
2021-12-02 disabled motor as a solution for now
2021-12-07 credited encoder files source in documentation
2021-12-07 editing z-motor task documentation
2021-12-07 finished gripper documentation
2021-12-07 Motor driver documentation done
2021-12-07 documentation for the x motors
2021-12-07 y motor task documentation done
2021-12-07 z motor documented
2021-12-07 Added PCB files
    [Claw Machine Final.brd, Claw Machine Final.sch]
2021-12-08 moved folders
    [Belt Clamp.SLDPRT, Belt Holder.SLDPRT, Chessboard.SLDPRT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]
2021-12-08 STL files
    [Belt Clamp (x2).STL, Belt Holder (x2).STL, Lead Screw to Gripper (x1).STL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]
2021-12-08 3D Printer instructions
    [Large Pieces.3mf, Small Pieces.3mf]
2021-12-08 added page and motor tasks
2021-12-08 3D printed parts page
2021-12-08 added images for 3D printed parts section and isometric view to introduction
2021-12-08 whole file assembly
    [Chessbot Assembly.SLDASM]
